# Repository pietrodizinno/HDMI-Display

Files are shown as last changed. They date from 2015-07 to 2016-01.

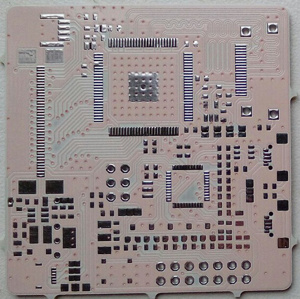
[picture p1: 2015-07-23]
pcb/HDMI-Display_v10-0603.jpg

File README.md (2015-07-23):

# HDMI-Display / HDMI to RGB Adapter
Universal HDMI/DVI Displays with Touch Panel based on TI TFP401 and Atmel ATmega32u4 (with Arduino Leonardo compatible Bootloader).

HDMI-Display
HDMI-Display (http://www.watterott.com/en/HDMI-RGB-adapter-with-ATmega32U4-touch-controller)

## Shop
* [HDMI to RGB Adapter](http://www.watterott.com/en/HDMI-RGB-adapter-with-ATmega32U4-touch-controller)
* [40-Pin FFC-Extenter](http://www.watterott.com/en/40-Pin-FFC-extenter)
* [Bundle: HDMI Adapter + 5" 800x480 Display with Touchpanel](http://www.watterott.com/en/5-800x480-HDMI-Display-with-resistive-touch)
* [Bundle: HDMI Adapter + 7" 800x480 Display with Touchpanel](http://www.watterott.com/en/7-800x480-HDMI-Display-with-resistive-touch)
* Compatible TFT-Displays *(check jumper settings before connecting the screen)*:
  * [5" 800x480 Display with resitive Touchpanel](http://www.watterott.com/en/5-800x480-TFT-Display)
  * [7" 800x480 Display with resitive Touchpanel](http://www.watterott.com/en/7-800x480-TFT-Display)
  * [7" 800x480 Display with capacitive Touchpanel](http://www.watterott.com/en/7-inch-800x480-TFT-LCD-Display-with-capacitive-touch-panel)
  * [7" 1024x600 Display with capacitive Touchpanel](http://www.watterott.com/en/7-inch-1024x600-TFT-LCD-Display-with-capacitive-touch-panel) *(needs hardware modification on backlight circuit)*

## Features
* TI **TFP401A** HDMI to RGB Converter
* Pixel Rates up to 165MHz, 1080p and WUXGA (1920x1200) at 60Hz
* HDMI compatible (DVI, no Sound, no HDCP, no CEC)
* Atmel **ATmega32U4** Microcontroller to control Backlight and Touch Panel (USB HID Mouse)
* **EDID** EEPROM (24LC02B) for display settings
* LED Backlight Boost Regulator (up to 35V)
* 3.3V - 5V tolerant UART and I2C interface
* **Single 5V Power Supply** via MicroUSB connector

## Hardware and Software
* [Schematics/Layout + Guide](https://github.com/watterott/HDMI-Display/tree/master/pcb)
* [Firmware for ATmega32U4 Microcontroller](https://github.com/watterott/HDMI-Display/tree/master/src)
* [Displays Compatibility List](https://github.com/watterott/HDMI-Display/blob/master/docu/Displays.md)
* [FAQ (Frequently Asked Questions)](https://github.com/watterott/HDMI-Display/blob/master/docu/FAQ.md)
* [Enclosures (3D models)](https://www.thingiverse.com/search?q=watterott+display)

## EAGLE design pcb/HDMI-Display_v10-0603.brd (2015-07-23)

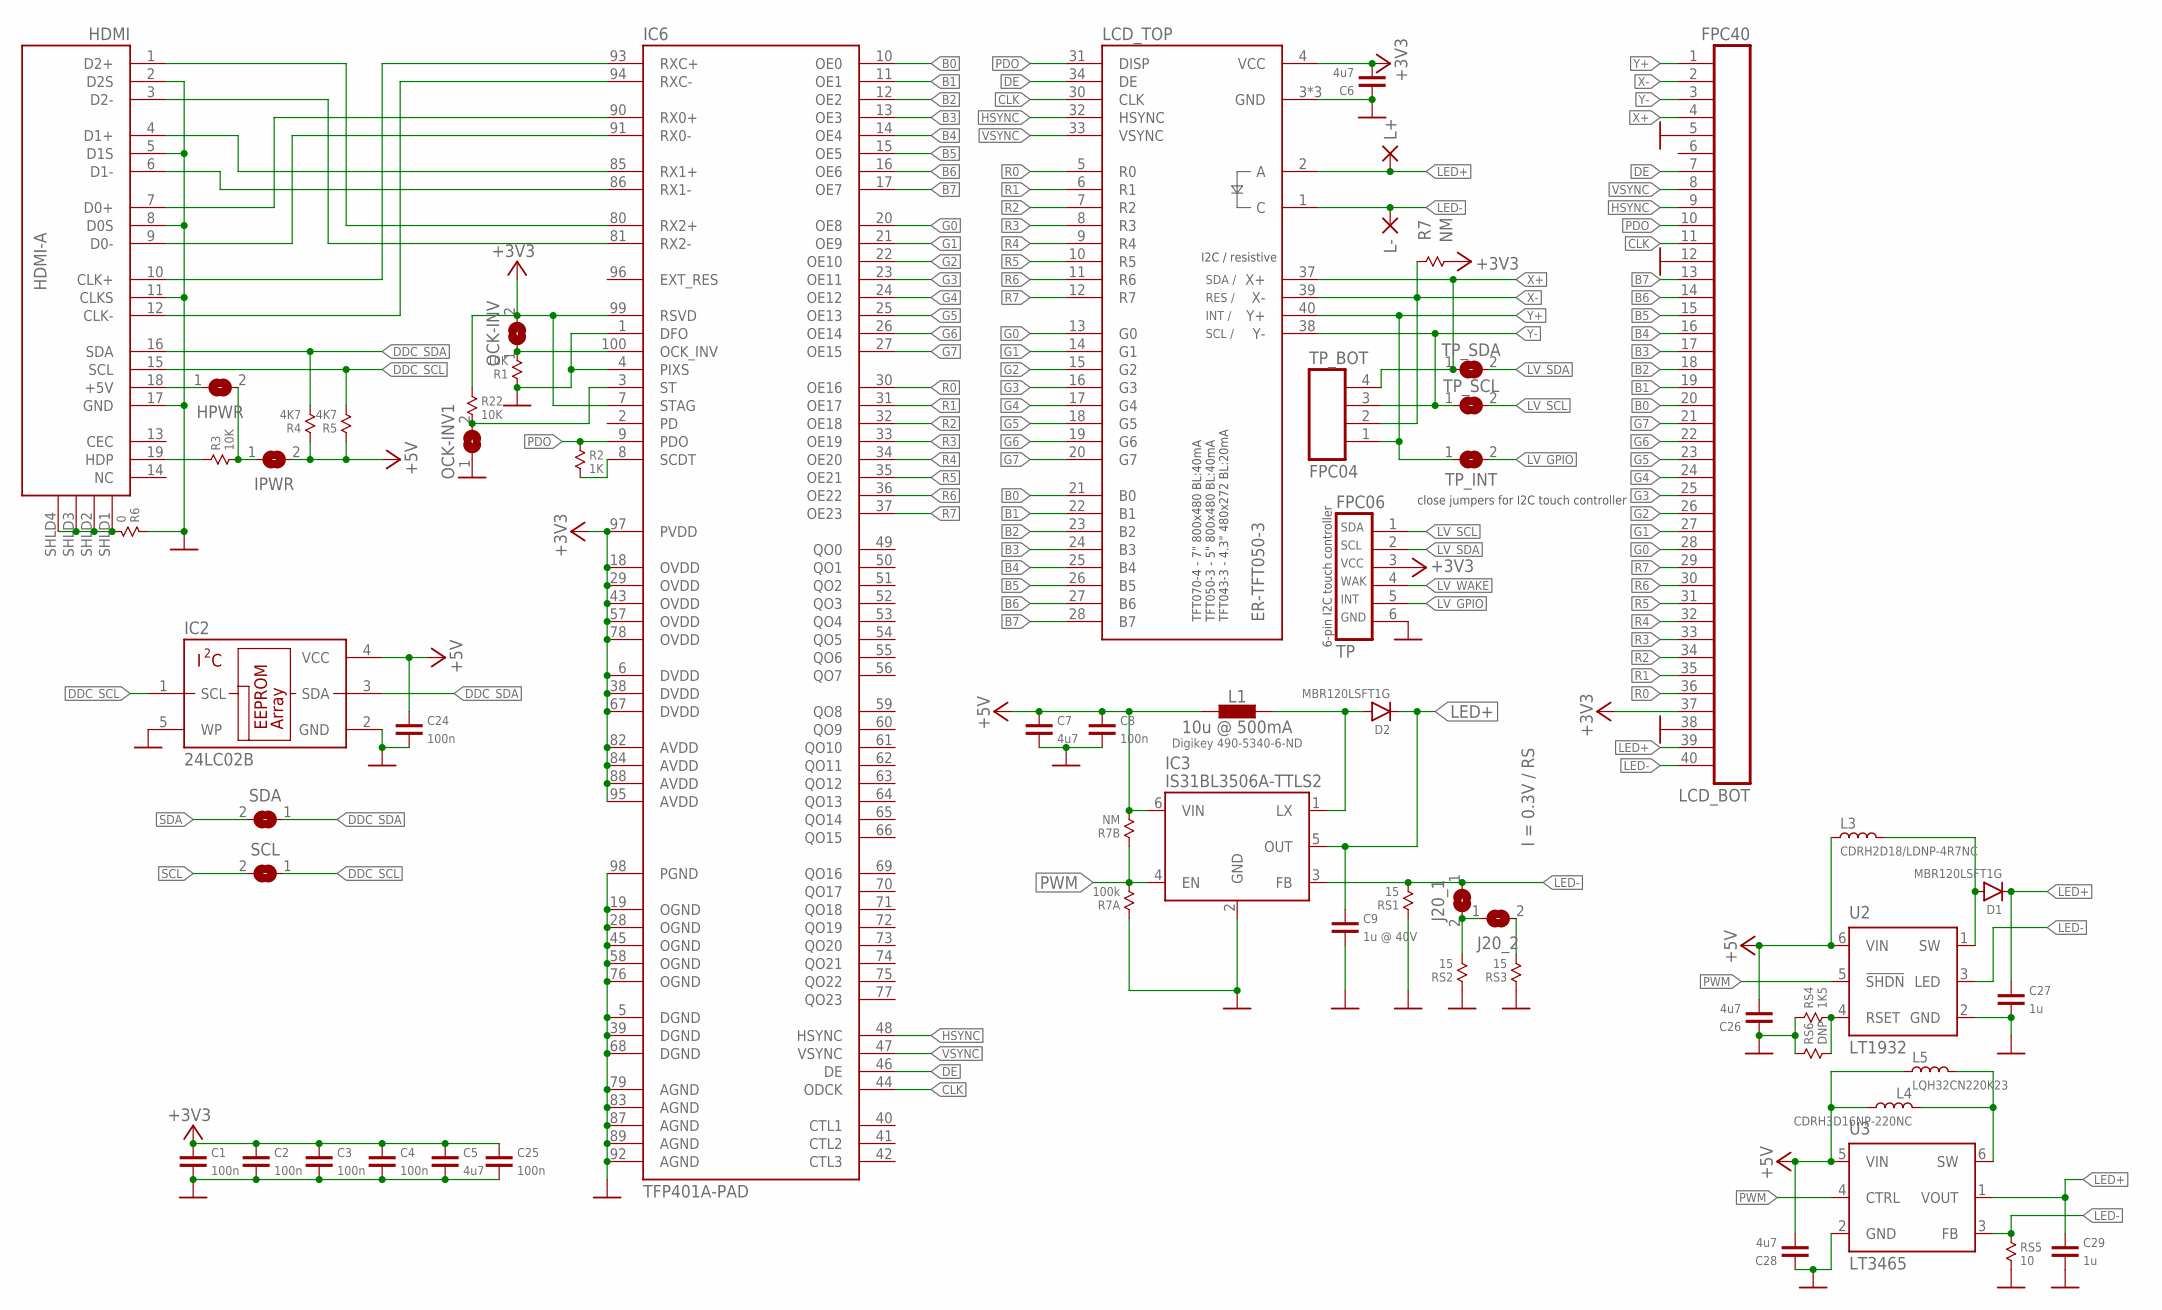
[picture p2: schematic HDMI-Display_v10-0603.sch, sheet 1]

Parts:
C1, C2, C3, C4, C8, C24, C25: 100n; 0603
C5, C6, C7, C26, C28: 4u7; 0603
C9: 1u @ 40V; 0805
C27, C29: 1u; 0603
D1, D2: MBR120LSFT1G; SOD-123
HDMI: HDMI-A; HDMI_10029449
HPWR: JUMPER2-0603
IC2: 24LC02B; SOT23-5
IC3: IS31BL3506A-TTLS2; SOT23-6
IC6: TFP401A-PAD; TQFP100-PAD
IPWR: JUMPER2-0603
J20_1, J20_2: JUMPER2-0402
L1: 10u @ 500mA; L_1212
L3: CDRH2D18/LDNP-4R7NC; CDRH2D18
L4: CDRH3D16NP-220NC; CDRH3D16
L5: LQH32CN220K23; LQH32CN_23/LQH32CN_33
L+: PAD-0.80X1.60_NC
L-: PAD-0.80X1.60_NC
LCD_BOT: FPC40
LCD_TOP: ER-TFT050-3; FPC40
OCK-INV, OCK-INV1: JUMPER2-0603-NC; JUMPER2-0603_NC
R1, R3, R22: 10K; 0603
R2: 1K; 0603
R4, R5: 4K7; 0603
R6: 0; 0603
R7, R7B: NM; 0603
R7A: 100k; 0603
RS1, RS2, RS3: 15; 0603
RS4: 1K5; 0603
RS5: 10; 0603
RS6: DNP; 0603
SCL: JUMPER2-0603
SDA: JUMPER2-0603
TP: FPC06
TP_BOT: FPC04
TP_INT: JUMPER2-0402
TP_SCL: JUMPER2-0402
TP_SDA: JUMPER2-0402
U2: LT1932; SOT23-6
U3: LT3465; SOT23-6

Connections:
+3V3: C1.2, C2.2, C3.2, C4.2, C5.2, C6.1, C25.2, IC6.6 (DVDD), IC6.7 (STAG), IC6.18 (OVDD), IC6.29 (OVDD), IC6.38 (DVDD), IC6.43 (OVDD), IC6.57 (OVDD), IC6.67 (DVDD), IC6.78 (OVDD), IC6.82 (AVDD), IC6.84 (AVDD), IC6.88 (AVDD), IC6.95 (AVDD), IC6.97 (PVDD), IC6.99 (RSVD), LCD_BOT.37, LCD_TOP.4 (VCC), OCK-INV.2, R7.2, R22.1, TP.3; also elsewhere on the board
+5V: C7.2, C8.2, C24.2, C26.1, C28.1, IC2.4 (VCC), IC3.6 (VIN), IPWR.2, L1.1, L3.1, L4.2, L5.1, R4.1, R5.1, R7B.2, U2.6 (VIN), U3.5 (VIN); also elsewhere on the board
B0: IC6.10 (OE0), LCD_BOT.20, LCD_TOP.21 (B0)
B1: IC6.11 (OE1), LCD_BOT.19, LCD_TOP.22 (B1)
B2: IC6.12 (OE2), LCD_BOT.18, LCD_TOP.23 (B2)
B3: IC6.13 (OE3), LCD_BOT.17, LCD_TOP.24 (B3)
B4: IC6.14 (OE4), LCD_BOT.16, LCD_TOP.25 (B4)
B5: IC6.15 (OE5), LCD_BOT.15, LCD_TOP.26 (B5)
B6: IC6.16 (OE6), LCD_BOT.14, LCD_TOP.27 (B6)
B7: IC6.17 (OE7), LCD_BOT.13, LCD_TOP.28 (B7)
CLK: IC6.44 (ODCK), LCD_BOT.11, LCD_TOP.30 (CLK)
CLK_N: HDMI.12 (CLK-), IC6.94 (RXC-)
CLK_P: HDMI.10 (CLK+), IC6.93 (RXC+)
D0_N: HDMI.9 (D0-), IC6.91 (RX0-)
D0_P: HDMI.7 (D0+), IC6.90 (RX0+)
D1_N: HDMI.6 (D1-), IC6.86 (RX1-)
D1_P: HDMI.4 (D1+), IC6.85 (RX1+)
D2_N: HDMI.3 (D2-), IC6.81 (RX2-)
D2_P: HDMI.1 (D2+), IC6.80 (RX2+)
DDC_SCL: HDMI.15 (SCL), IC2.1 (SCL), R5.2, SCL.1
DDC_SDA: HDMI.16 (SDA), IC2.3 (SDA), R4.2, SDA.1
DE: IC6.46 (DE), LCD_BOT.7, LCD_TOP.34 (DE)
G0: IC6.20 (OE8), LCD_BOT.28, LCD_TOP.13 (G0)
G1: IC6.21 (OE9), LCD_BOT.27, LCD_TOP.14 (G1)
G2: IC6.22 (OE10), LCD_BOT.26, LCD_TOP.15 (G2)
G3: IC6.23 (OE11), LCD_BOT.25, LCD_TOP.16 (G3)
G4: IC6.24 (OE12), LCD_BOT.24, LCD_TOP.17 (G4)
G5: IC6.25 (OE13), LCD_BOT.23, LCD_TOP.18 (G5)
G6: IC6.26 (OE14), LCD_BOT.22, LCD_TOP.19 (G6)
G7: IC6.27 (OE15), LCD_BOT.21, LCD_TOP.20 (G7)
GND: C1.1, C2.1, C3.1, C4.1, C5.1, C6.2, C7.1, C8.1, C9.1, C24.1, C25.1, C26.2, C27.1, C28.2, C29.1, HDMI.2 (D2S), HDMI.5 (D1S), HDMI.8 (D0S), HDMI.11 (CLKS), HDMI.17 (GND), IC2.2 (GND), IC2.5 (WP), IC3.2 (GND), IC6.1 (DFO), IC6.4 (PIXS), IC6.5 (DGND), IC6.19 (OGND), IC6.28 (OGND), IC6.39 (DGND), IC6.45 (OGND), IC6.58 (OGND), IC6.68 (DGND), IC6.76 (OGND), IC6.79 (AGND), IC6.83 (AGND), IC6.87 (AGND), IC6.89 (AGND), IC6.92 (AGND), IC6.98 (PGND), LCD_BOT.5, LCD_BOT.12, LCD_BOT.38, LCD_TOP.3 (GND), LCD_TOP.29 (GND), LCD_TOP.36 (GND), OCK-INV1.1, R1.1, R6.1, R7A.1, RS1.1, RS2.1, RS3.1, RS4.1, RS5.2, RS6.1, TP.6, U2.2 (GND), U3.2 (GND); also elsewhere on the board
HDMI_5V: HDMI.18 (+5V), HPWR.1
HDMI_DECT: HDMI.19 (HDP), R3.1
HSYNC: IC6.48 (HSYNC), LCD_BOT.9, LCD_TOP.32 (HSYNC)
LED+: C9.2, C27.2, C29.2, D1.C, D2.C, IC3.5 (OUT), L+.1, LCD_BOT.39, LCD_TOP.2 (A), U3.1 (VOUT)
LED-: IC3.3 (FB), J20_1.1, L-.1, LCD_BOT.40, LCD_TOP.1 (C), RS1.2, RS5.1, U2.3 (LED), U3.3 (FB)
LV_GPIO: TP.5, TP_INT.2; also elsewhere on the board
LV_SCL: TP.1, TP_SCL.2; also elsewhere on the board
LV_SDA: TP.2, TP_SDA.2; also elsewhere on the board
LV_WAKE: TP.4
LX: D2.A, IC3.1 (LX), L1.2
unnamed: J20_2.2, RS3.2
unnamed: J20_1.2, J20_2.1, RS2.2
unnamed: IC6.100 (OCK_INV), OCK-INV.1, R1.2
unnamed: IC6.3 (ST), OCK-INV1.2, R22.2
unnamed: HPWR.2, IPWR.1, R3.2
unnamed: RS4.2, RS6.2, U2.4 (RSET)
unnamed: D1.A, L3.2, U2.1 (SW)
unnamed: L4.1, L5.2, U3.6 (SW)
PDO: IC6.9 (PDO), LCD_BOT.10, LCD_TOP.31 (DISP), R2.1
PWM: IC3.4 (EN), R7A.2, R7B.1, U2.5 (!SHDN), U3.4 (CTRL); also elsewhere on the board
R0: IC6.30 (OE16), LCD_BOT.36, LCD_TOP.5 (R0)
R1: IC6.31 (OE17), LCD_BOT.35, LCD_TOP.6 (R1)
R2: IC6.32 (OE18), LCD_BOT.34, LCD_TOP.7 (R2)
R3: IC6.33 (OE19), LCD_BOT.33, LCD_TOP.8 (R3)
R4: IC6.34 (OE20), LCD_BOT.32, LCD_TOP.9 (R4)
R5: IC6.35 (OE21), LCD_BOT.31, LCD_TOP.10 (R5)
R6: IC6.36 (OE22), LCD_BOT.30, LCD_TOP.11 (R6)
R7: IC6.37 (OE23), LCD_BOT.29, LCD_TOP.12 (R7)
SCDT: IC6.8 (SCDT), R2.2
SCL: SCL.2; also elsewhere on the board
SDA: SDA.2; also elsewhere on the board
SHLD3: HDMI.SHLD1 (SHLD), HDMI.SHLD2 (SHLD), HDMI.SHLD3 (SHLD), HDMI.SHLD4 (SHLD), R6.2
VSYNC: IC6.47 (VSYNC), LCD_BOT.8, LCD_TOP.33 (VSYNC)
X+: LCD_BOT.4, LCD_TOP.37 (X+), TP_BOT.4, TP_SDA.1; also elsewhere on the board
X-: LCD_BOT.2, LCD_TOP.39 (X-), R7.1, TP_BOT.2; also elsewhere on the board
Y+: LCD_BOT.1, LCD_TOP.40 (Y+), TP_BOT.1, TP_INT.1; also elsewhere on the board
Y-: LCD_BOT.3, LCD_TOP.38 (Y-), TP_BOT.3, TP_SCL.1; also elsewhere on the board

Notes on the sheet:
I = 0.3V / RS
Digikey 490-5340-6-ND
TFT070-4 - 7" 800x480 BL:40mA TFT050-3 - 5" 800x480 BL:40mA TFT043-3 - 4.3" 480x272 BL:20mA
SDA /
SCL /
RES /
INT /
SDA
SCL
VCC
INT
WAK
GND
close jumpers for I2C touch controller
6-pin I2C touch controller
I2C / resistive

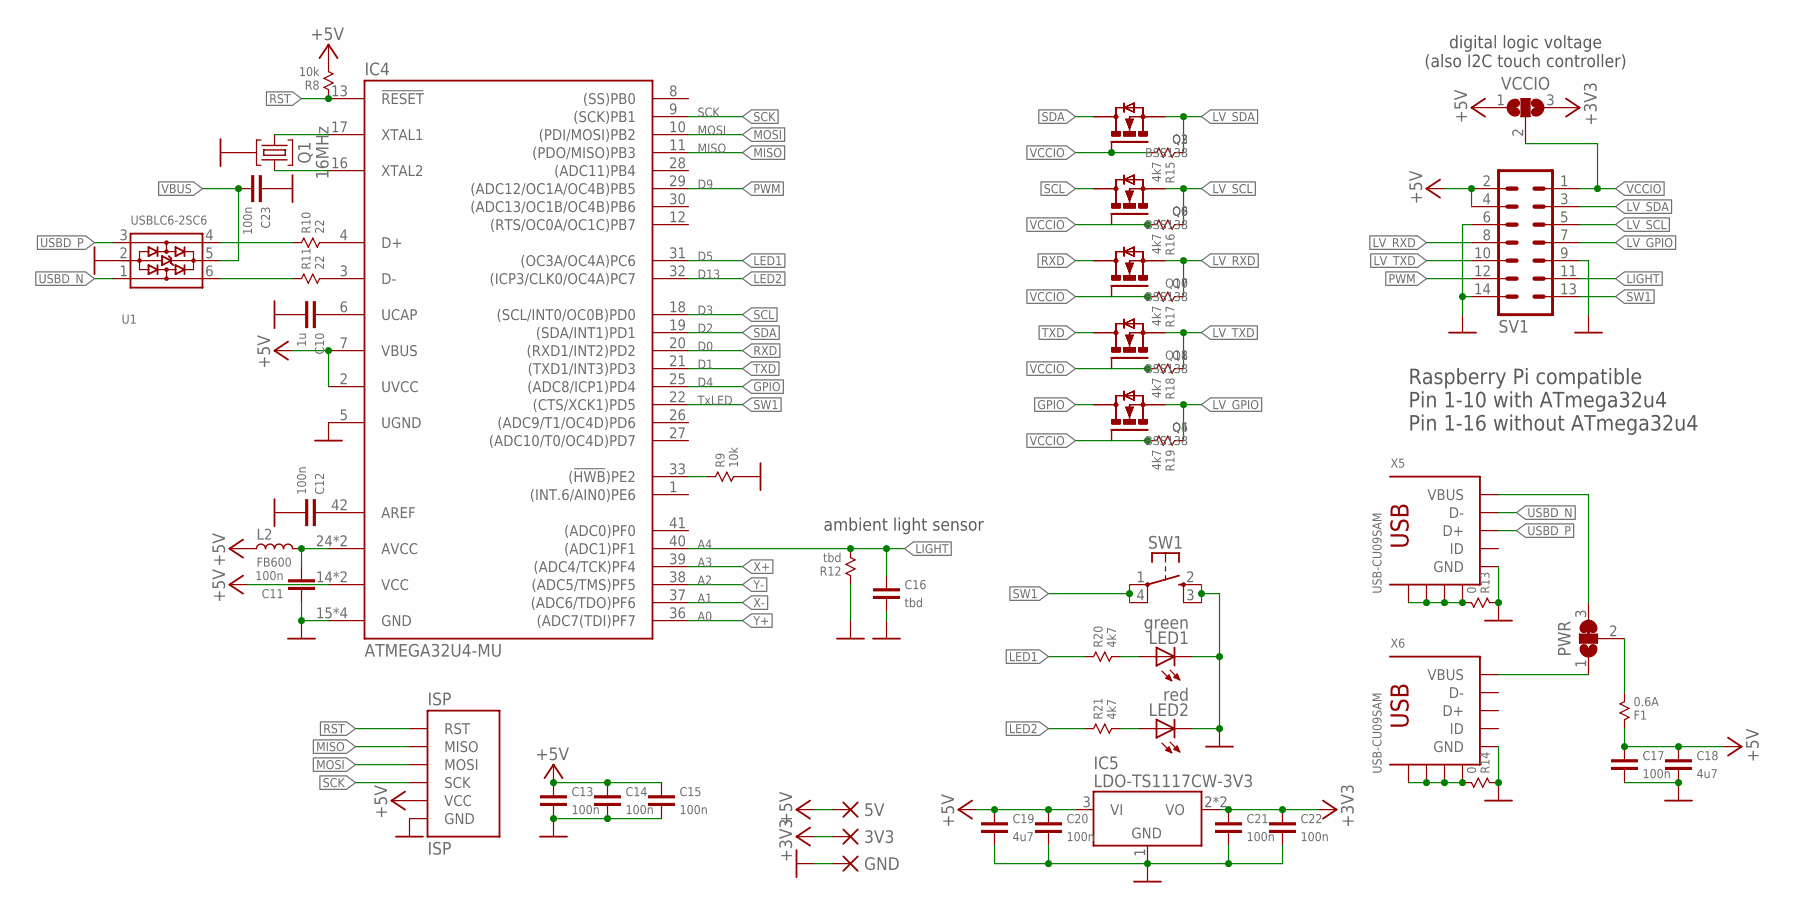
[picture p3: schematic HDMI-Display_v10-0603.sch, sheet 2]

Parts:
3V3, 5V: PAD-1.27X1.27_NC
C10: 1u; 0603
C11, C12, C13, C14, C15, C17, C20, C21, C22, C23: 100n; 0603
C16: tbd; 0603
C18, C19: 4u7; 0603
F1: 0.6A; 0805
GND: PAD-1.27X1.27_NC
IC4: ATMEGA32U4-MU; QFN44
IC5: LDO-TS1117CW-3V3; SOT223
ISP: ISP
L2: FB600; 0603
LED1: green; LED_0603
LED2: red; LED_0603
PWR: JUMPER3-0603
Q1: 16MHz; CRYSTAL_32X13
Q2, Q5, Q6, Q7, Q8: MOSFET-N-SOT323; SOT323
Q3, Q4, Q9, Q10, Q11: BSS138; SOT-23
R8, R9: 10k; 0603
R10, R11: 22; 0603
R12: tbd; 0603
R13, R14: 0; 0603
R15, R16, R17, R18, R19, R20, R21: 4k7; 0603
SV1: MA07-2
SW1: SW-TACTILE-TL3315; SW_TL3315N
U1: USBLC6-2SC6; SOT23-6
VCCIO: JUMPER3-0603-NC; JUMPER3-0603_NC
X5, X6: USB-CU09SAM; CU09SAM

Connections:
+3V3: 3V3.1, C21.2, C22.2, IC5.2 (VO), IC5.4 (VO), VCCIO.3; also elsewhere on the board
+5V: 5V.1, C13.2, C14.2, C15.2, C17.2, C18.2, C19.2, C20.2, F1.1, IC4.2 (UVCC), IC4.7 (VBUS), IC4.14 (VCC), IC4.34 (VCC), IC5.3 (VI), ISP.VCC, L2.1, R8.2, SV1.2, SV1.4, VCCIO.1; also elsewhere on the board
AREF: C12.2, IC4.42 (AREF)
AVCC: C11.1, IC4.24 (AVCC), IC4.44 (AVCC), L2.2
D_N: IC4.3 (D-), R11.2
D_P: IC4.4 (D+), R10.2
GND: C10.1, C11.2, C12.1, C13.1, C14.1, C15.1, C16.1, C17.1, C18.1, C19.1, C20.1, C21.1, C22.1, C23.2, GND.1, IC4.5 (UGND), IC4.15 (GND), IC4.23 (GND), IC4.35 (GND), IC4.43 (GND), IC5.1 (GND), ISP.GND, LED1.C, LED2.C, Q1.GND, R9.2, R12.1, R13.1, R14.1, SV1.6, SV1.9, SV1.14, SW1.2 (S1), SW1.3 (S2), U1.2 (GND), X5.5 (GND), X6.5 (GND); also elsewhere on the board
GPIO: IC4.25 ((ADC8/ICP1)PD4), Q4.3 (D), Q5.3 (D)
HWB: IC4.33 ((!HWB!)PE2), R9.1
LED1: IC4.31 ((OC3A/OC4A)PC6), R20.1
LED2: IC4.32 ((ICP3/CLK0/OC4A)PC7), R21.1
LIGHT: C16.2, IC4.40 ((ADC1)PF1), R12.2, SV1.11
LV_GPIO: Q4.2 (S), Q5.2 (S), R19.1, SV1.7; also elsewhere on the board
LV_RXD: Q7.2 (S), Q10.2 (S), R17.1, SV1.8
LV_SCL: Q6.2 (S), Q9.2 (S), R16.1, SV1.5; also elsewhere on the board
LV_SDA: Q2.2 (S), Q3.2 (S), R15.1, SV1.3; also elsewhere on the board
LV_TXD: Q8.2 (S), Q11.2 (S), R18.1, SV1.10
MISO: IC4.11 ((PDO/MISO)PB3), ISP.MISO
MOSI: IC4.10 ((PDI/MOSI)PB2), ISP.MOSI
unnamed: R11.1, U1.6 (IO1)
unnamed: R10.1, U1.4 (IO2)
unnamed: C10.2, IC4.6 (UCAP)
unnamed: F1.2, PWR.2
unnamed: LED1.A, R20.2
unnamed: LED2.A, R21.2
PWM: IC4.29 ((ADC12/OC1A/OC4B)PB5), SV1.12; also elsewhere on the board
RST: IC4.13 (!RESET), ISP.RST, R8.1
RXD: IC4.20 ((RXD1/INT2)PD2), Q7.3 (D), Q10.3 (D)
SCK: IC4.9 ((SCK)PB1), ISP.SCK
SCL: IC4.18 ((SCL/INT0/OC0B)PD0), Q6.3 (D), Q9.3 (D); also elsewhere on the board
SDA: IC4.19 ((SDA/INT1)PD1), Q2.3 (D), Q3.3 (D); also elsewhere on the board
SHLD1: R13.2, X5.GND@1 (GND), X5.GND@2 (GND), X5.GND@3 (GND), X5.GND@4 (GND)
SHLD2: R14.2, X6.GND@1 (GND), X6.GND@2 (GND), X6.GND@3 (GND), X6.GND@4 (GND)
SW1: IC4.22 ((CTS/XCK1)PD5), SV1.13, SW1.1, SW1.4 (P2)
TXD: IC4.21 ((TXD1/INT3)PD3), Q8.3 (D), Q11.3 (D)
USBD_N: U1.1 (IO1), X5.2 (D-)
USBD_P: U1.3 (IO2), X5.3 (D+)
VBUS: C23.1, PWR.3, U1.5 (VBUS), X5.1 (VBUS)
VBUS_PWR: PWR.1, X6.1 (VBUS)
VCCIO: Q2.1 (G), Q3.1 (G), Q4.1 (G), Q5.1 (G), Q6.1 (G), Q7.1 (G), Q8.1 (G), Q9.1 (G), Q10.1 (G), Q11.1 (G), R15.2, R16.2, R17.2, R18.2, R19.2, SV1.1, VCCIO.2
X+: IC4.39 ((ADC4/TCK)PF4); also elsewhere on the board
X-: IC4.37 ((ADC6/TDO)PF6); also elsewhere on the board
XTAL1: IC4.17 (XTAL1), Q1.2
XTAL2: IC4.16 (XTAL2), Q1.1
Y+: IC4.36 ((ADC7(TDI)PF7); also elsewhere on the board
Y-: IC4.38 ((ADC5/TMS)PF5); also elsewhere on the board

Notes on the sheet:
ambient light sensor
TxLED
D13
SCK
MOSI
MISO
Raspberry Pi compatible Pin 1-10 with ATmega32u4 Pin 1-16 without ATmega32u4
digital logic voltage (also I2C touch controller)

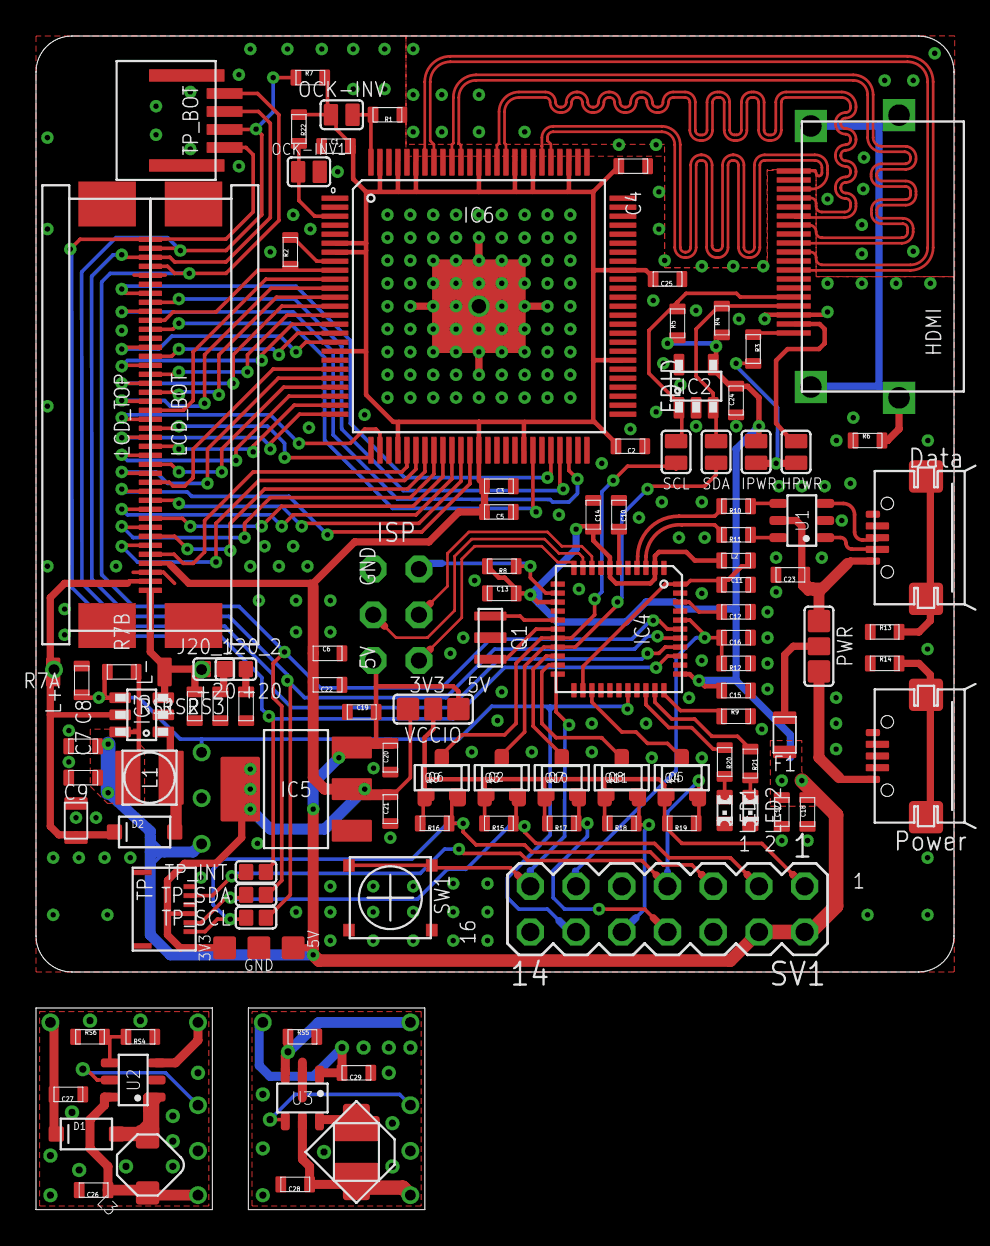
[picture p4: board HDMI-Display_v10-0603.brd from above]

Board: 2 copper layers, 51.0 x 52.0 mm, 116 parts (0 on the bottom side), 100 nets.

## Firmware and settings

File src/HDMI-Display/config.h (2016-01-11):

#ifndef CONFIG_H
#define CONFIG_H

//***** Select your Display and Touchpanel here ******
#define DISPLAY_TYPE            DISPLAY_480x272 // DISPLAY_480x272 DISPLAY_800x480 DISPLAY_800x480HY DISPLAY_1024x600HY
#define TOUCHPANEL_TYPE         TOUCHPANEL_NONE // TOUCHPANEL_NONE TOUCHPANEL_RESISTIVE TOUCHPANEL_FT5x06

/*
  Watterott electronic display configurations:
  5" with res. touch: DISPLAY_800x480 + TOUCHPANEL_RESISTIVE
  7" with res. touch: DISPLAY_800x480 + TOUCHPANEL_RESISTIVE
  7" with cap. touch: DISPLAY_800x480HY or DISPLAY_1024x600HY + TOUCHPANEL_FT5x06
*/

// General Settings
//#define DEBUG             1 // set debugg output level (0=nothing, 1=minimal...)
#define ORIENTATION       0 // orientation (0x1=invert x, 0x2=invert y, 0x4=swap axes, 0x8=map to screen coordinates)
#define SCREENSAVERTIME 180 // seconds timeout (0...65535, 0=always on)
#define BRIGHTNESS      255 // backlight brightness (0..255)
#define LOOPTIME         16 // 16 = 60 Hz polling interval
#define TOUCHMAX      4095L // maximal touch/mouse position

#define QUOTE(name)     #name
#define STR(macro)      QUOTE(macro)
#define VERSION_STRING  "1.10"
#define INFO_STRING     "HDMI-Display\nVersion: " VERSION_STRING " (" __DATE__ ")\nTFT: " STR(SCREEN_WIDTH) "x" STR(SCREEN_HEIGHT)"\nTouch: " STR(TOUCHPANEL_TYPE) "\nhttps://github.com/watterott/HDMI-Display"

// Display Types
#define DISPLAY_480x272          1 //  480 x  272 (TFT043-3)
#define DISPLAY_640x480          2 //  640 x  480
#define DISPLAY_720x480          3 //  720 x  480
#define DISPLAY_800x480          4 //  800 x  480 (TFT050-3, HY5-LCD-HD, TFT070-4, HY7-LCD)
#define DISPLAY_800x480_720x480  5 //  800 x  480 with 720x480 (480p) fallback (TFT050-3, HY5-LCD-HD, TFT070-4, HY7-LCD)
#define DISPLAY_800x480HY        6 //  800 x  480 (HY070CTP capacitive touchpanel)
#define DISPLAY_800x600          7 //  800 x  600
#define DISPLAY_1024x600         8 // 1024 x  600
#define DISPLAY_1024x600HY       9 // 1024 x  600 (HY070CTP-HD capacitive touchpanel)
#define DISPLAY_1024x768        10 // 1024 x  768
#define DISPLAY_1280x720        11 // 1280 x  720
#define DISPLAY_1280x768        12 // 1280 x  768
#define DISPLAY_1280x800        13 // 1280 x  800
#define DISPLAY_1280x1024       14 // 1280 x 1024

// Touchpanel Types
#define TOUCHPANEL_NONE         1 // No Touchpanel present
#define TOUCHPANEL_RESISTIVE    2 // Resitive
#define TOUCHPANEL_FT5x06       3 // Capacitive FT5x06 (HY070CTP)

// check configurations
#if TOUCHPANEL_TYPE == TOUCHPANEL_NONE
#  undef SCREENSAVERTIME
#  define SCREENSAVERTIME 0
#  define TPC_X0 0    // not needed - touchpanel calibration x0
#  define TPC_X1 0    // not needed - touchpanel calibration x1
#  define TPC_Y0 0    // not needed - touchpanel calibration y0
#  define TPC_Y1 0    // not needed - touchpanel calibration y1
#elif TOUCHPANEL_TYPE == TOUCHPANEL_RESISTIVE
#  define TPC_X0 80   // touchpanel calibration x0
#  define TPC_X1 930  // touchpanel calibration x1
#  define TPC_Y0 825  // touchpanel calibration y0
#  define TPC_Y1 160  // touchpanel calibration y1
#elif TOUCHPANEL_TYPE == TOUCHPANEL_FT5x06
#  define TPC_X0 0    // not needed - touchpanel calibration x0
#  define TPC_X1 0    // not needed - touchpanel calibration x1
#  define TPC_Y0 0    // not needed - touchpanel calibration y0
#  define TPC_Y1 0    // not needed - touchpanel calibration y1
#else
#  error "Please select a TOUCHPANEL_TYPE"
#endif

#if DISPLAY_TYPE == DISPLAY_480x272
#  define SCREEN_WIDTH   480
#  define SCREEN_HEIGHT  272
#elif DISPLAY_TYPE == DISPLAY_640x480
#  define SCREEN_WIDTH   640
#  define SCREEN_HEIGHT  480
#elif DISPLAY_TYPE == DISPLAY_720x480
#  define SCREEN_WIDTH   720
#  define SCREEN_HEIGHT  480
#elif DISPLAY_TYPE == DISPLAY_800x480 || \
      DISPLAY_TYPE == DISPLAY_800x480_720x480 || \
      DISPLAY_TYPE == DISPLAY_800x480HY
#  define SCREEN_WIDTH   800
#  define SCREEN_HEIGHT  480
#elif DISPLAY_TYPE == DISPLAY_800x600
#  define SCREEN_WIDTH   800
#  define SCREEN_HEIGHT  600
#elif DISPLAY_TYPE == DISPLAY_1024x600 || \
      DISPLAY_TYPE == DISPLAY_1024x600HY
#  define SCREEN_WIDTH   1024
#  define SCREEN_HEIGHT  600
#elif DISPLAY_TYPE == DISPLAY_1024x768
#  define SCREEN_WIDTH   1024
#  define SCREEN_HEIGHT  768
#elif DISPLAY_TYPE == DISPLAY_1280x720
#  define SCREEN_WIDTH   1280
#  define SCREEN_HEIGHT  720
#elif DISPLAY_TYPE == DISPLAY_1280x768
#  define SCREEN_WIDTH   1280
#  define SCREEN_HEIGHT  768
#elif DISPLAY_TYPE == DISPLAY_1280x800
#  define SCREEN_WIDTH   1280
#  define SCREEN_HEIGHT  800
#elif DISPLAY_TYPE == DISPLAY_1280x1024
#  define SCREEN_WIDTH   1280
#  define SCREEN_HEIGHT  1024
#else
#  error "Please select a DISPLAY_TYPE"
#endif

#ifndef SWAP
#define SWAP(x,y) do{ (x)=(x)^(y); (y)=(x)^(y); (x)=(x)^(y); }while(0)
#endif
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

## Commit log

2015-07-23 Add version with 0603 components. Add backlight controllers on LT1932 and LT3465.
    [HDMI-Display_v10-0603.brd, HDMI-Display_v10-0603.sch]
2015-07-23 Change pcb image
